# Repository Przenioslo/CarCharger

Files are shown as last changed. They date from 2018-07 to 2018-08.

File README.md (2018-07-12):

# CarCharger

The device consists of a buck converter allowing to reduce the input 12 - 40 V to a 5 V (3 A max) output. The output USB A connector's D+/D- lines are configured for 2.1 A output current. After the input voltage drops bellow 12 V, the output voltage is shutdown. It is turned ON again after input voltage rises above 13 V level.

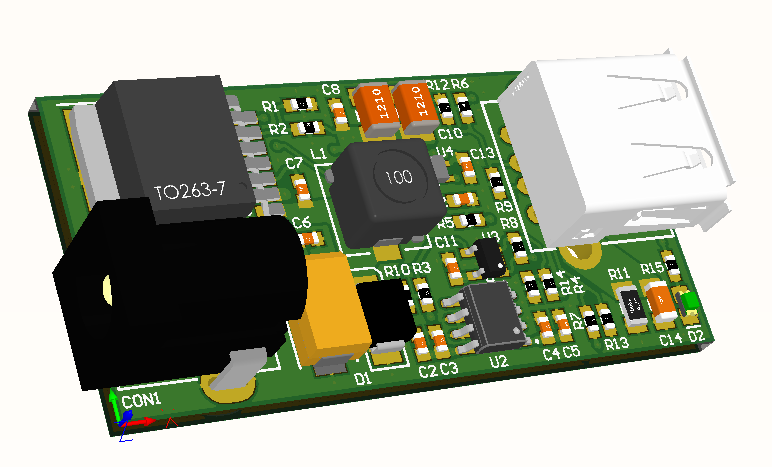
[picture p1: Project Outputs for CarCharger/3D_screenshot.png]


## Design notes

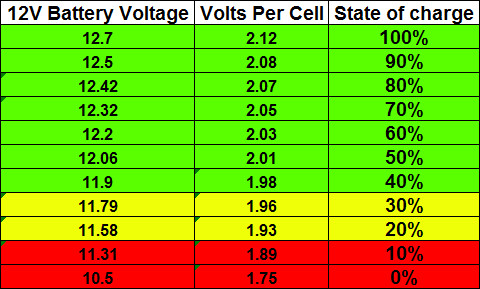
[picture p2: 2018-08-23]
battery_voltage.png

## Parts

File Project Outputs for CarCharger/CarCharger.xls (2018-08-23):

Designator | Comment | Value | manid | Footprint | Tolerance | Voltage | Quantity
C1 | 47uF | 47uF | T491X476K035AT | SMDD | 10% | 35V | 1
C2, C5 | 1uF | 1uF |  | CAPC1608N | 10% | 25V | 2
C3, C4, C6, C7, C8, C11, C13 | 100nF | 100nF |  | CAPC1608N | 5% | 25V | 7
C9, C10 | 100uF | 100uF |  | CAPC3225N | 20% | 10V | 2
C12 | 10uF | 10uF |  | CAPC1608N | 20% | 6V3 | 1
C14 | 2n2 | 2n2 |  | CAPC3216N | 10% | 500V | 1
CON1 | 1613 21 |  | 1613 21 | JACK-2.5 |  |  | 1
CON2 | 67643-3910 |  | 67643-3910 | USB-A-socket |  |  | 1
D1 | SK210 |  |  | SMB |  |  | 1
D2 | Led Green |  | LTST-C170GKT | CD2012-0805-GRN |  |  | 1
DATE1 | DATE |  |  | DATE |  |  | 1
L1 | DR74-330-R | 33uH |  | DR74 Series |  |  | 1
R1 | 1k | 1k |  | RESC1608N | 1% |  | 1
R2 | 3k3 | 3k3 |  | RESC1608N | 1% |  | 1
R3 | 390k | 390k |  | RESC1608N | 1% |  | 1
R4 | 100k | 100k |  | RESC1608N | 1% |  | 1
R5 | 200k | 200k |  | RESC1608N | 1% |  | 1
R6, R7 | 30k | 30k |  | RESC1608N | 1% |  | 2
R8 | 1M8 | 1M8 |  | RESC1608N | 1% |  | 1
R9 | open | open |  | RESC1608N | 5% |  | 1
R10 | 97k6 | 97k6 |  | RESC1608N | 1% |  | 1
R11 | 10M | 10M |  | RESC3216N | 5% |  | 1
R12, R13 | 20k | 20k |  | RESC1608N | 1% |  | 2
R14 | 240k | 240k |  | RESC1608N | 1% |  | 1
R15 | 620R | 620R |  | RESC1608N | 1% |  | 1
U1 | LM2676S-ADJ |  | LM2676S-ADJ | TO-263-7 |  |  | 1
U2 | L78L33ABD-TR |  | L78L33ABD-TR | SO-8_L |  |  | 1
U3 | MCP6001T-I/OT |  | MCP6001T-I/OT | SOT23-5_N |  |  | 1
U4 | NC7SP04P5X |  | NC7SP04P5X | sc70 |  |  | 1

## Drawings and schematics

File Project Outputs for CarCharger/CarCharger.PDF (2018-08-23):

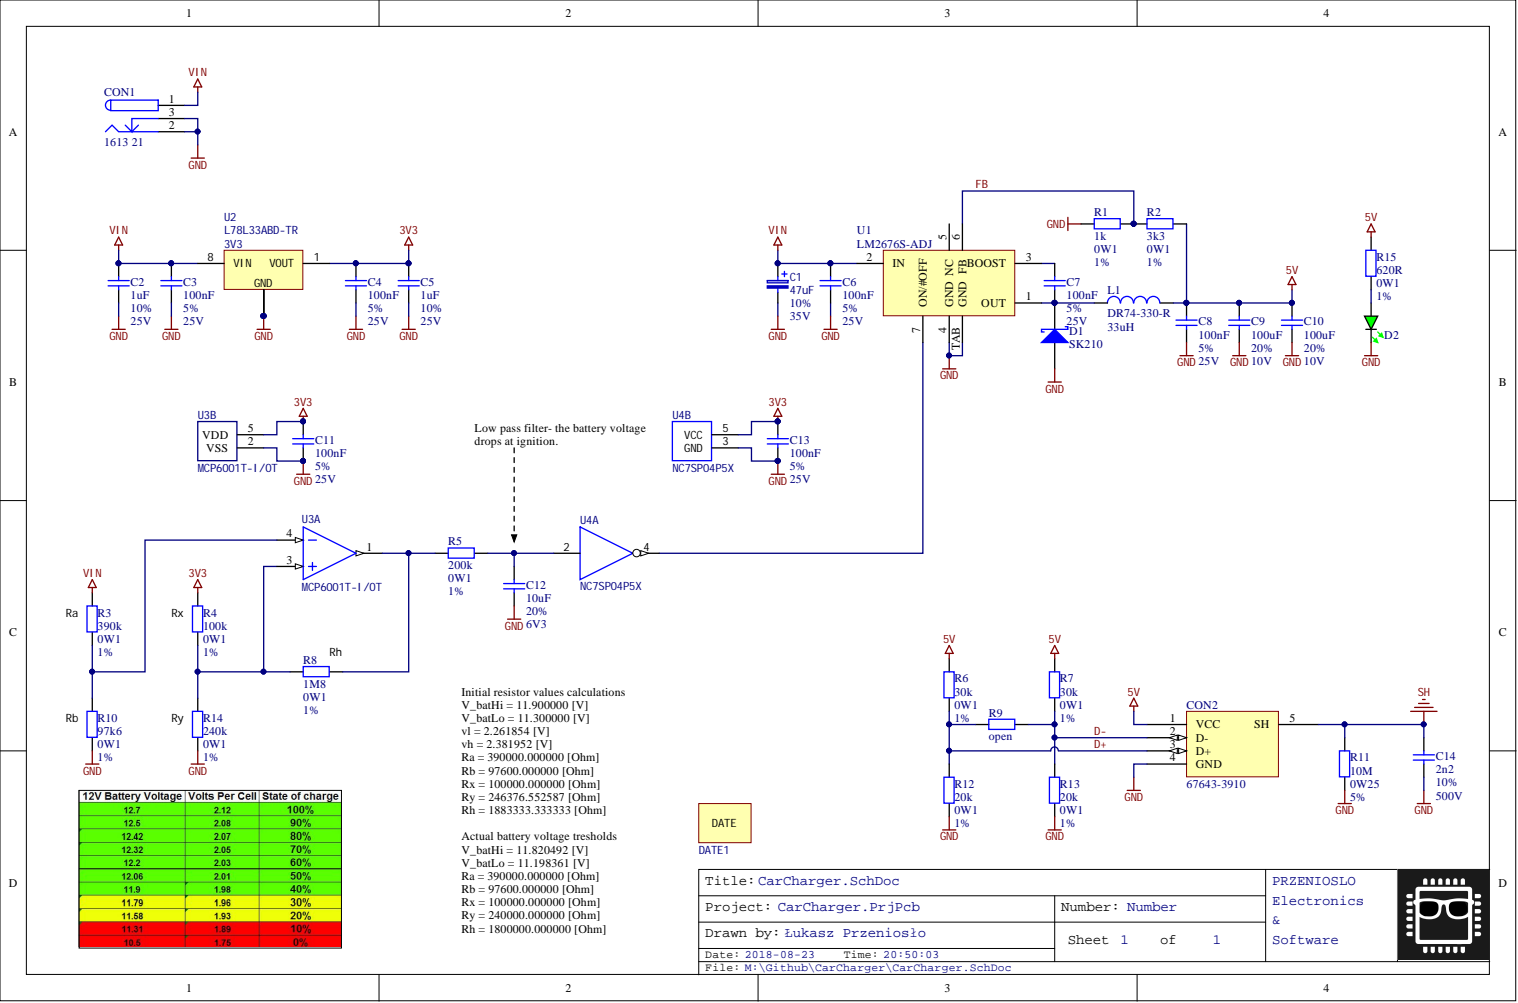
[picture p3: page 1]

Low pass filter- the battery voltage
drops at ignition.

Title: CarCharger.SchDoc | PRZENIOSLO Electronics & Software

Project: CarCharger.PrjPcb | Number: Number

Drawn by: Łukasz Przeniosło | Sheet 1 of Time: 1

M:\Github\CarCharger\CarCharger.SchDoc

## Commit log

2018-07-04 Finished the schematics.
    [CarCharger.PrjPcb, CarCharger.SchDoc]
2018-07-05 Simplified the hysteresis schematics.
    [CarCharger.SchDoc]
2018-07-07 Components placed.
    [CarCharger.PcbDoc, CarCharger.PrjPcb, CarCharger.SchDoc]
2018-07-07 Added 5V output voltage LED indicator.
    [CarCharger.PcbDoc, CarCharger.SchDoc]
2018-07-07 Routing started, changed board layers amount from 2 to 4.
    [CarCharger.PcbDoc, CarCharger.SchDoc]
2018-07-08 Routing finished.
    [CarCharger.PcbDoc, CarCharger.PrjPcb]
2018-07-08 Added BOM and schematics print.
    [CarCharger.PcbDoc, CarCharger.PrjPcb, CarCharger.SchDoc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]
2018-07-08 Added a 3D PCB screenshot for usage in README or WIKI page.
2018-07-12 Updated git ignore for gerber outputs Added date region on the PCB.
    [CarCharger.PcbDoc, CarCharger.PrjPcb, CarCharger.SchDoc]
2018-07-29 Fixed resistor values to ones easier available.
    [CarCharger.PrjPcb, CarCharger.SchDoc, CarCharger.xls]
2018-08-13 Updated R2 value to 3.3k from 3.9k (5.2V output instead of 5.9V).
    [CarCharger.SchDoc, CarCharger.xls]
2018-08-23 Changed thresholds values (resistors) after tests in the car. Added simple matlab scripts for easier resistors values calculations.
    [CarCharger.PrjPcb, CarCharger.SchDoc]
2018-08-23 Updated BOM and PDF
    [CarCharger.PrjPcb, CarCharger.xls]
2018-08-29 Updated the values on the PCB
    [CarCharger.PcbDoc, CarCharger.PrjPcb]
